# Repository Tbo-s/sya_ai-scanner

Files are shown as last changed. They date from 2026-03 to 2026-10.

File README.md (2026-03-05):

# sya_ai-scanner

Software-
arduino mega = grbl
grbl dowloaden (zip) vanuit https://github.com/gnea/grbl-Mega/tree/edge uit deze folder de grbl in de arduino folder zetten. Dit bestand dan uploaden naar mega. ''$'' typen in serial monitor (115200 baud) voor versie te checken.

starten pi
cd ~/projects/sya_ai-scanner/code/picode/visionAI

make run_backend
make run_frontend

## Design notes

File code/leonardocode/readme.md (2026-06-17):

te ontvangen :
GATE_OPEN
GATE_CLOSE
TRAY_OUT
TRAY_IN
STATUS
STOP_ALL

stoppers:
- bovenste gate-stopper: A4
- onderste gate-stopper: A5
- lade-uit-stopper: D4
- lade-in-stopper: D5
- alle stopper-switches zijn normally closed en gebruiken INPUT_PULLUP
- sluit elke stopper naar GND: niet geraakt = LOW, stopper geraakt/contact open = HIGH

leonardo verstuurd:
ACK:GATE_OPEN
ACK:GATE_CLOSE
ACK:TRAY_OUT
ACK:TRAY_IN
ACK:STATUS,gateState=...,gatePos=...,trayState=...,trayPos=...

De Pi/backend bepaalt of de gate klaar is via `STATUS`: `gateState=0` en `gatePos=UP`
of `gatePos=DOWN`.

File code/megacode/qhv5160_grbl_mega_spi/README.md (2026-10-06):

# QHV5160 on Arduino Mega GRBL

This patch configures three QHV5160/TMC5160 drivers from the Arduino Mega at
GRBL boot. It uses bit-banged SPI so every driver input has its own Mega pin
and no signal wire needs to be split. One optional wire enables X diagnostics.

For QHV5160 modules with 0.075 ohm sense resistors, all three axes use about
846 mA RMS run current (IRUN=16), 348 mA RMS hold current, and
GLOBAL_SCALER=133. These are calculated current targets, not measured coil
currents or analog Vref voltages.

All axes use full steps without interpolation to match the previous DRV8825
drivers with M0/M1/M2 disconnected. At the current GRBL setting of 250 steps/mm,
a 0.004 mm command is one full step (1.8 degrees on the bare motor shaft); a
0.1 mm command is 25 steps / 45 degrees. Begin with one step. Actual arm travel
depends on the mechanics and calibration.

## Apply

From the repo root on the Mac:

```bash
python3 code/megacode/qhv5160_grbl_mega_spi/apply_to_arduino_grbl.py
```

Then upload:

```text
code/megacode/grblUpload_copy_20260304140826/grblUpload_copy_20260304140826.ino
```

with board `Arduino Mega or Mega 2560`.

## Wiring

Set QHV5160 `VIO` to 5V and connect all grounds together.

X driver:

- Mega D24 -> `REFL_STEP`
- Mega D30 -> `DIR_REFR_DIR`
- Mega D40 -> `SCK_CFG2`
- Mega D41 -> `SDI_CFG1`
- Mega D42 -> `CSN_CFG3`

Y driver:

- Mega D25 -> `REFL_STEP`
- Mega D31 -> `DIR_REFR_DIR`
- Mega D43 -> `SCK_CFG2`
- Mega D44 -> `SDI_CFG1`
- Mega D45 -> `CSN_CFG3`

Z driver:

- Mega D26 -> `REFL_STEP`
- Mega D32 -> `DIR_REFR_DIR`
- Mega D46 -> `SCK_CFG2`
- Mega D47 -> `SDI_CFG1`
- Mega D48 -> `CSN_CFG3`

Enable:

- Minimum wiring: each QHV5160 `EN` -> GND.
- Or one shared GRBL enable line: Mega D13 -> each `EN`.

Mode pins on every driver:

- `SD_MODE` -> VIO
- `SPI_MODE` -> VIO

Leave Y/Z `SDO_CFG0` disconnected.

## Optional X Diagnostics

With all power and USB disconnected, add **X `SDO_CFG0` -> Mega D49**.
Keep the existing SCK/SDI/CSN wiring and common ground. D49 is an input with a
weak pull-up, not a 5V output. This adds just one wire (four SPI wires for X).

After uploading this patch, send `$T` through GRBL while idle or in alarm.
The command reads registers only: it does not move the motor, clear driver
faults, or change current settings.

- `IOIN`: chip version in bits 31..24 (expected 0x30), EN level in bit 4
  (0=enabled), SD_MODE in bit 6 (1=STEP/DIR mode).
- `GSTAT`: reset in bit 0, driver shutdown in bit 1, charge-pump undervoltage
  history in bit 2. Read `DRV_STATUS` for details before clearing faults.
- `GCONF`: expected 0x00000000.
- `CHOPCONF`: expected 0x08408158 for X (full steps, driver enabled). Y and Z
  receive the same setting at boot; their SDO pins are intentionally unwired.
- `DRV_STATUS`: raw driver status, including protection flags and CS_ACTUAL.
- `MSCNT`: microstep counter; compare before/after a small commanded move to
  check whether the driver is receiving STEP pulses.
- `BOOT_CURRENT_ECHO`: 1 means the driver echoed both current-setting payloads
  during Mega boot. It is not a measurement of coil current. GLOBAL_SCALER and
  IHOLD_IRUN are write-only, so `$T` does not pretend to read their contents.

All-ones reads typically mean no SDO response; all-zero reads also do not
establish communication. Check IOIN version and several register values.
`BOOT_CURRENT_ECHO=0` can also mean SDO was missing at boot; after connecting
it, restart the Mega with the driver powered before judging this field.

Reference: [TMC5160 datasheet, sections 4 and 6](https://www.analog.com/media/en/technical-documentation/data-sheets/TMC5160A_datasheet_rev1.18.pdf).

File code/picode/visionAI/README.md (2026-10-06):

# SYA VisionAI

Softwarestack voor een Raspberry Pi 4 kiosk die een smartphone automatisch scant, fotografeert en gradeert met behulp van:

- een Arduino Leonardo voor gate, lade, wrist-servo's en vacuum
- een Arduino Mega met GRBL voor X/Y/Z-beweging van de robotarm
- een USB-camera voor IMEI-detectie
- een Pi CSI-camera voor extra foto's
- een Vue frontend in kiosk mode
- een FastAPI backend die de volledige flow en hardware aanstuurt

Deze README is bedoeld als:

- opstarthandleiding voor de Raspberry Pi
- overzicht van alle belangrijke commando's
- uitleg van de code-architectuur
- referentie voor debuggen en kalibreren

## 1. Doel Van Het Project

De gebruiker legt een smartphone op een lade. Daarna:

1. leest de kiosk het IMEI-nummer
2. bepaalt de Pi het toesteltype en een richtwaarde
3. opent de gate/lade zodat het toestel in de box kan
4. positioneert de robotarm zich naar het toestel
5. pakt de arm het toestel op met vacuum
6. draait de arm/wrist het toestel voor de camera
7. maakt het systeem foto's van de voor- en achterkant
8. stuurt de backend foto's en IMEI naar een damage/pricing service
9. toont de kiosk het resultaat en een prijsvoorstel

De uiteindelijke flow in code is gemodelleerd in [`backend/services/scan_orchestrator.py`](/Users/tbo/Desktop/github/sya_ai-scanner/code/picode/visionAI/backend/services/scan_orchestrator.py).

## 2. Hardware Overzicht

### Raspberry Pi 4

- draait frontend + backend
- praat via USB met Leonardo en Mega
- leest de USB-camera uit voor IMEI
- kan optioneel de Pi CSI-camera gebruiken voor extra foto's

### Arduino Leonardo

Wordt aangesproken via `pyserial` en stuurt:

- gate open/dicht
- lade in/uit
- 2 wrist-servo's
- vacuum aan/uit

Ondersteunde commando's in de Python-code:

- `GATE_OPEN`
- `GATE_CLOSE`
- `TRAY_OUT`
- `TRAY_IN`
- `GATE_POS`
- `STATUS`
- `VACUUM_ON`
- `VACUUM_OFF`

Stopper-switches op de Leonardo:

- bovenste gate-stopper: `A4`
- onderste gate-stopper: `A5`
- lade-uit-stopper: `D4`
- lade-in-stopper: `D5`
- alle stopper-switches zijn normally closed en gebruiken `INPUT_PULLUP`
- sluit elke switch naar `GND`: niet geraakt = `LOW`, stopper geraakt/contact open = `HIGH`

Belangrijke responses:

- `ACK:GATE_OPEN`
- `ACK:GATE_CLOSE`
- `ACK:TRAY_OUT`
- `ACK:TRAY_IN`
- `ACK:STATUS,gateState=...,gatePos=...,trayState=...,trayPos=...`
- `GATE_POS=UP`
- `GATE_POS=DOWN`
- `ERR:...`

De backend bepaalt of een gatebeweging klaar is via `STATUS`: `gateState=0` en
`gatePos=UP` of `gatePos=DOWN`.

De Leonardo-logica zit vooral in:

- [`backend/services/machine_service.py`](/Users/tbo/Desktop/github/sya_ai-scanner/code/picode/visionAI/backend/services/machine_service.py)
- [`backend/controller/arduino.py`](/Users/tbo/Desktop/github/sya_ai-scanner/code/picode/visionAI/backend/controller/arduino.py)

### Arduino Mega + GRBL

Stuurt:

- X/Y-beweging
- Z-as

De carriage is mechanisch cartesiaans. De interface zet de zichtbare pijlen om
naar de gedraaide Mega-motorassen: boven/onder gebruikt Mega X en links/rechts
gebruikt Mega Y met omgekeerde richting. `APP_GRBL_COREXY_ENABLED` blijft
beschikbaar voor een eventuele echte CoreXY-opstelling, maar staat uit.

De Mega/GRBL-logica zit in:

- [`backend/services/grbl_service.py`](/Users/tbo/Desktop/github/sya_ai-scanner/code/picode/visionAI/backend/services/grbl_service.py)
- [`backend/controller/arduino.py`](/Users/tbo/Desktop/github/sya_ai-scanner/code/picode/visionAI/backend/controller/arduino.py)

## 3. Repo Structuur

### Backend

- [`backend/websrv.py`](/Users/tbo/Desktop/github/sya_ai-scanner/code/picode/visionAI/backend/websrv.py)
  FastAPI app, router-registratie, websocket endpoint, frontend serving, boot initialization.

- [`backend/controller/scan.py`](/Users/tbo/Desktop/github/sya_ai-scanner/code/picode/visionAI/backend/controller/scan.py)
  HTTP API voor scan start, confirm, status en abort.

- [`backend/services/scan_orchestrator.py`](/Users/tbo/Desktop/github/sya_ai-scanner/code/picode/visionAI/backend/services/scan_orchestrator.py)
  De belangrijkste machineflow. Hier staan de stappen 19-60 van jouw flowchart.

- [`backend/controller/camera.py`](/Users/tbo/Desktop/github/sya_ai-scanner/code/picode/visionAI/backend/controller/camera.py)
  USB-camera stream, IMEI detectie, scanfoto's en Pi CSI captures.

- [`backend/services/machine_service.py`](/Users/tbo/Desktop/github/sya_ai-scanner/code/picode/visionAI/backend/services/machine_service.py)
  Alle Leonardo-gerelateerde hardwareacties.

- [`backend/services/grbl_service.py`](/Users/tbo/Desktop/github/sya_ai-scanner/code/picode/visionAI/backend/services/grbl_service.py)
  Alle GRBL/NEMA-bewegingen.

- [`backend/services/ai_damage_service.py`](/Users/tbo/Desktop/github/sya_ai-scanner/code/picode/visionAI/backend/services/ai_damage_service.py)
  Mock of echte API-call voor damage/pricing-resultaat.

- [`backend/services/system_service.py`](/Users/tbo/Desktop/github/sya_ai-scanner/code/picode/visionAI/backend/services/system_service.py)
  Boot-safe-idle, home en runtime settings.

- [`backend/controller/system.py`](/Users/tbo/Desktop/github/sya_ai-scanner/code/picode/visionAI/backend/controller/system.py)
  Debug/system endpoints om de machine in veilige toestand te zetten.

- [`backend/controller/device_lookup.py`](/Users/tbo/Desktop/github/sya_ai-scanner/code/picode/visionAI/backend/controller/device_lookup.py)
  Mock lookup van IMEI naar toesteltype en maximale waarde.

### Frontend

- [`frontend/src/pages/index.vue`](/Users/tbo/Desktop/github/sya_ai-scanner/code/picode/visionAI/frontend/src/pages/index.vue)
  De kioskflow voor de gebruiker: starten, IMEI scannen, toestel bevestigen, scanstatus volgen, resultaat tonen.

- [`frontend/src/services/websocket.js`](/Users/tbo/Desktop/github/sya_ai-scanner/code/picode/visionAI/frontend/src/services/websocket.js)
  Websocket client voor real-time `scan_event` updates.

### Deploy / Scripts

- [`scripts/pi_run_backend.sh`](/Users/tbo/Desktop/github/sya_ai-scanner/code/picode/visionAI/scripts/pi_run_backend.sh)
  Start de backend op de Pi.

- [`scripts/pi_build_frontend.sh`](/Users/tbo/Desktop/github/sya_ai-scanner/code/picode/visionAI/scripts/pi_build_frontend.sh)
  Bouwt de frontend productieversie.

- [`scripts/pi_start_kiosk.sh`](/Users/tbo/Desktop/github/sya_ai-scanner/code/picode/visionAI/scripts/pi_start_kiosk.sh)
  Start Chromium in kiosk mode.

- [`deploy/systemd/sya-backend.service`](/Users/tbo/Desktop/github/sya_ai-scanner/code/picode/visionAI/deploy/systemd/sya-backend.service)
  Systemd unit voor backend.

- [`deploy/systemd/sya-kiosk.service`](/Users/tbo/Desktop/github/sya_ai-scanner/code/picode/visionAI/deploy/systemd/sya-kiosk.service)
  Systemd unit voor kiosk/browser.

## 4. Raspberry Pi Setup

### 4.0 Snelle recovery na nieuwe SD-kaart

Flash Raspberry Pi OS, maak gebruiker `sya` aan en zet SSH aan. Daarna:

```bash
cd /home/sya
git clone <jouw-repo-url> sya
cd /home/sya/sya
./scripts/pi_first_boot_setup.sh
```

Laat `APP_GRBL_HOME_ON_BOOT=0` staan tot X/Y/Z limit-switches met
`/api/arduino/grbl/status` of een raw `?` GRBL-status bewezen schakelen.
Zet homing pas daarna terug aan.

### 4.1 Repo clonen

```bash
cd /home/sya
git clone <jouw-repo-url> sya
cd sya
```

### 4.2 Systeempackages installeren

```bash
sudo apt update
sudo apt install -y python3 python3-venv python3-pip libzbar0 chromium-browser
```

Voor Pi CSI camera:

```bash
sudo apt install -y python3-picamera2
```

### 4.3 Project dependencies installeren

```bash
make install
```

Wat dit doet:

- maakt `backend/venv`
- installeert Python dependencies uit `backend/requirements.txt`
- installeert frontend dependencies uit `frontend/package.json`

### 4.4 Config invullen

Open:

```bash
nano backend/config/config.env
```

Belangrijkste variabelen:

- `APP_LEONARDO_PORT`
- `APP_GRBL_PORT`
- `APP_LEONARDO_BAUD`
- `APP_GRBL_BAUD`
- `APP_CAMERA_INDEX`
- `APP_PHOTO_STORAGE_DIR`
- `APP_PI_CAPTURE_DIR`
- `APP_FRONTEND_DIST`
- `APP_GRBL_FRONT_X`
- `APP_GRBL_FRONT_Y`
- `APP_GRBL_BACK_X`
- `APP_GRBL_BACK_Y`
- `APP_GRBL_Z_AXIS_ENABLED`
- `APP_GRBL_Z_PICKUP`
- `APP_GRBL_Z_TRAVEL`
- `APP_GRBL_HOME_Z_CLEARANCE`
- `APP_GRBL_HOME_Z_STEP`
- `APP_GRBL_HOME_Z_SEARCH_DISTANCE`
- `APP_GRBL_HOME_Z_FEED_RATE`
- `APP_GRBL_Z_LIMIT_TOWARD_ZERO_SIGN`
- `APP_ARM_DISTANCE_THRESHOLD_CM`
- `APP_GATE_MOVE_TIMEOUT_S`
- `APP_TRAY_MOVE_TIMEOUT_S`
- `APP_USER_CONFIRM_TIMEOUT_S`
- `APP_MACHINE_SAFE_IDLE_ON_BOOT`
- `APP_DEVICE_LOOKUP_API_ENABLED`
- `APP_DEVICE_LOOKUP_API_URL`
- `APP_DEVICE_LOOKUP_API_TIMEOUT_S`
- `APP_AI_DAMAGE_API_MOCK`
- `APP_AI_DAMAGE_API_URL`
- `APP_SCAN_RESULTS_UPLOAD_ENABLED`
- `APP_SCAN_RESULTS_UPLOAD_URL`
- `APP_SCAN_RESULTS_UPLOAD_TIMEOUT_S`
- `APP_SCAN_RESULTS_UPLOAD_REQUIRED`

De documentatie van die env vars staat in:

- [`backend/config/config.env`](/Users/tbo/Desktop/github/sya_ai-scanner/code/picode/visionAI/backend/config/config.env)
- [`backend/config/README.md`](/Users/tbo/Desktop/github/sya_ai-scanner/code/picode/visionAI/backend/config/README.md)

## 5. Frontend / Backend Opstarten

### 5.1 Development mode

Backend:

```bash
make run_backend
```

Frontend:

```bash
make run_frontend
```

Samen:

```bash
make run
```

In development:

- frontend draait normaal op `http://localhost:8080`
- backend draait op `http://localhost:3000`

### 5.2 Productie / Pi mode

Frontend builden:

```bash
./scripts/pi_build_frontend.sh
```

Backend starten:

```bash
./scripts/pi_run_backend.sh
```

Dan serveert de backend de gebouwde frontend op:

```text
http://<raspberry-pi-ip>:3000
```

### 5.3 Chromium kiosk starten

Op de Pi met een actieve desktop-sessie:

```bash
./scripts/pi_start_kiosk.sh http://127.0.0.1:3000
```

## 6. Systemd Boot Op De Pi

De bedoeling is dat backend en kiosk automatisch starten bij opstarten van de Pi.

Installeer de services:

```bash
sudo cp deploy/systemd/sya-backend.service /etc/systemd/system/
sudo cp deploy/systemd/sya-kiosk.service /etc/systemd/system/
sudo systemctl daemon-reload
sudo systemctl enable sya-backend.service
sudo systemctl enable sya-kiosk.service
sudo systemctl start sya-backend.service
sudo systemctl start sya-kiosk.service
```

Status controleren:

```bash
sudo systemctl status sya-backend.service
sudo systemctl status sya-kiosk.service
```

Logs bekijken:

```bash
journalctl -u sya-backend.service -f
journalctl -u sya-kiosk.service -f
```

## 7. Runtime Flow In De Code

### 7.1 Gebruikersflow

De frontend in [`frontend/src/pages/index.vue`](/Users/tbo/Desktop/github/sya_ai-scanner/code/picode/visionAI/frontend/src/pages/index.vue) doet:

1. startscherm tonen
2. case/screenprotector schoonmaakflow
3. IMEI scannen met USB-camera
4. manuele IMEI fallback aanbieden
5. toesteldata ophalen
6. gebruiker toestel laten uitschakelen
7. backend scan starten via `/api/scan/start`
8. live machine-updates ontvangen via websocket
9. eindprijs/resultaat tonen

### 7.2 Scan flow

De backend scanflow zit in [`backend/services/scan_orchestrator.py`](/Users/tbo/Desktop/github/sya_ai-scanner/code/picode/visionAI/backend/services/scan_orchestrator.py).

Belangrijk:

- `start_scan()`
  Start een nieuwe scan en maakt een `ScanSession`.

- `_await_user()`
  Pauzeert de flow wanneer de gebruiker het toestel nog moet plaatsen.

- `_step()`
  Draait een hardwarefunctie in een thread en broadcast de status.

- `_execute_sequence()`
  Bevat de volledige fysieke machineflow.

### 7.3 Leonardo logica

[`backend/services/machine_service.py`](/Users/tbo/Desktop/github/sya_ai-scanner/code/picode/visionAI/backend/services/machine_service.py) is de laag die letterlijk met de Leonardo praat.

Belangrijke functies:

- `open_gate()`
- `close_gate()`
- `tray_out()`
- `tray_in()`
- `wait_for_gate_done()`
- `wait_for_tray_done()`
- `set_wrist1()`
- `set_wrist2()`
- `wrist_home()`
- `vacuum_on()`
- `vacuum_off()`
- `read_distance()`

### 7.4 GRBL logica

[`backend/services/grbl_service.py`](/Users/tbo/Desktop/github/sya_ai-scanner/code/picode/visionAI/backend/services/grbl_service.py) praat met de Mega via GRBL.

Belangrijke functies:

- `send_grbl()`
- `move_to_front_of_phone()`
- `move_to_back_of_phone()`
- `move_to_front_slow_with_distance_stop()`
- `move_to_back_slow_with_distance_stop()`
- `z_up()`
- `z_down()`
- `run_sequence()`
- `run_postflow_sequence()`

### 7.5 Camera logica

[`backend/controller/camera.py`](/Users/tbo/Desktop/github/sya_ai-scanner/code/picode/visionAI/backend/controller/camera.py) beheert:

- live USB-camera stream via `/api/camera/stream`
- IMEI detectie via `/api/imei/detect`
- scanfoto's via `take_photo()`
- Pi CSI captures via `/api/camera/pi/capture`

### 7.6 Device lookup / pricing mock

[`backend/controller/device_lookup.py`](/Users/tbo/Desktop/github/sya_ai-scanner/code/picode/visionAI/backend/controller/device_lookup.py) gebruikt standaard een lokale JSON lookup om een toesteltype, grootte en maximumwaarde te geven.
Zet `APP_DEVICE_LOOKUP_API_ENABLED=1` en `APP_DEVICE_LOOKUP_API_URL=...` om later een echte IMEI/product-API aan te sluiten.

[`backend/services/ai_damage_service.py`](/Users/tbo/Desktop/github/sya_ai-scanner/code/picode/visionAI/backend/services/ai_damage_service.py) geeft:

- mock-resultaten als `APP_AI_DAMAGE_API_MOCK=1`
- echte API-calls met IMEI, sessie, maximumwaarde en alle foto's als `APP_AI_DAMAGE_API_MOCK=0`

[`backend/services/scan_upload_service.py`](/Users/tbo/Desktop/github/sya_ai-scanner/code/picode/visionAI/backend/services/scan_upload_service.py) kan na een volledige scan een aparte POST sturen met IMEI, sessie, toestelmodel, maximumwaarde, AI-resultaat en alle foto's als base64 JSON. Standaard staat dit uit:

- `APP_SCAN_RESULTS_UPLOAD_ENABLED=0`
- `APP_SCAN_RESULTS_UPLOAD_URL=`

Vul later de URL in en zet `APP_SCAN_RESULTS_UPLOAD_ENABLED=1` om de POST effectief te sturen. Met `APP_SCAN_RESULTS_UPLOAD_REQUIRED=1` faalt de scan-flow als deze upload mislukt; standaard wordt een uploadfout alleen gerapporteerd in `upload_result`.

## 8. API Endpoints

### Scan

- `POST /api/scan/start`
- `POST /api/scan/confirm`
- `POST /api/scan/abort`
- `GET /api/scan/status`

De automatische UI-flow gebruikt een expliciete state machine in plaats van losse
stapnummers: `BOOT`, `WELCOME`, `IMEI_SCAN`, `DEVICE_LOOKUP`, `WAIT_POWER_OFF`,
`LOAD_DEVICE`, `CLOSE_BOX`, `CAPTURE_FRONT`, `CAPTURE_BACK`, `UPLOAD_RESULTS`,
`RETURN_DEVICE`, `SHOW_PRICE`, `DONE`, `ERROR` en `EMERGENCY_STOP`. Hardware-substeps
worden alleen nog als detailinformatie meegestuurd via websocket-events.

### Camera

- `GET /api/camera/stream`
- `GET /api/imei/detect`
- `POST /api/camera/capture`
- `POST /api/camera/pi/capture`

### Device lookup

- `POST /api/device/lookup`

### Arduino / hardware debug

- `POST /api/arduino/servo`
- `POST /api/arduino/leonardo/servo`
- `POST /api/arduino/leonardo/gate`
- `GET /api/arduino/leonardo/gate-position`
- `POST /api/arduino/leonardo/tray`
- `GET /api/arduino/leonardo/tray-position`
- `POST /api/arduino/leonardo/home`
- `POST /api/arduino/leonardo/emergency-stop`
- `POST /api/arduino/grbl/command`
- `POST /api/arduino/grbl/unlock`
- `POST /api/arduino/grbl/home`
- `POST /api/arduino/grbl/home-xy`
- `POST /api/arduino/grbl/stop`
- `POST /api/arduino/grbl/post-flow`
- `GET /api/arduino/ports`

### System

- `GET /api/system/settings`
- `POST /api/system/safe-idle`
- `POST /api/system/home`
- `GET /api/system/boot-report`

## 9. Websocket Events

Frontend en backend communiceren live via `/ws`.

Belangrijkste event:

- `scan_event`

Types:

- `awaiting_user`
- `step_complete`
- `scan_complete`
- `scan_failed`

Frontend-afhandeling zit in [`frontend/src/services/websocket.js`](/Users/tbo/Desktop/github/sya_ai-scanner/code/picode/visionAI/frontend/src/services/websocket.js) en [`frontend/src/pages/index.vue`](/Users/tbo/Desktop/github/sya_ai-scanner/code/picode/visionAI/frontend/src/pages/index.vue).

## 10. Test- En Debugcommando's

Seriële poorten opvragen:

```bash
curl http://127.0.0.1:3000/api/arduino/ports
```

Gate positie lezen:

```bash
curl http://127.0.0.1:3000/api/arduino/leonardo/gate-position
```

Tray positie lezen:

```bash
curl http://127.0.0.1:3000/api/arduino/leonardo/tray-position
```

Machine in veilige idle toestand zetten:

```bash
curl -X POST http://127.0.0.1:3000/api/system/safe-idle
```

Home flow uitvoeren:

```bash
curl -X POST http://127.0.0.1:3000/api/system/home
```

GRBL unlock/home:

```bash
curl -X POST http://127.0.0.1:3000/api/arduino/grbl/unlock
curl -X POST http://127.0.0.1:3000/api/arduino/grbl/home
```

`/api/arduino/grbl/home` voert de volledige arm-homeflow uit: Z eerst `+2 mm`,
daarna X/Y naar hun limits, daarna Z in stappen van `-1 mm` tot de Z-limit onderaan
geraakt wordt. De exacte waarden zijn configureerbaar met `APP_GRBL_HOME_Z_*`.
De homingfeedrates staan standaard traag ingesteld: X/Y `F60` en Z `F30`.
Zet `APP_GRBL_Z_AXIS_ENABLED=0` om tijdelijk alle Z-bewegingen over te slaan wanneer
de Z-driver niet aangesloten is. Homing doet dan alleen X/Y en Z-knoppen in de UI worden
uitgeschakeld.
Voor homing wordt eerst een live GRBL-status gelezen. Als X/Y al op hun limit-switch
staan, worden die assen direct als `0` gezet en niet verder tegen de stopper bewogen.
Als de switchstatus niet gelezen kan worden, wordt homing afgebroken in plaats van blind
een beweging te sturen.

Frontend build:

```bash
./scripts/pi_build_frontend.sh
```

Backend starten:

```bash
./scripts/pi_run_backend.sh
```

## 11. Kalibratiepunten

Voor echte productie moet je minstens deze parameters op de hardware afstemmen:

- `APP_GRBL_FRONT_X`
- `APP_GRBL_FRONT_Y`
- `APP_GRBL_BACK_X`
- `APP_GRBL_BACK_Y`
- `APP_GRBL_Z_AXIS_ENABLED`
- `APP_GRBL_Z_PICKUP`
- `APP_GRBL_Z_TRAVEL`
- `APP_ARM_DISTANCE_THRESHOLD_CM`
- `APP_WRIST_DWELL_MS`
- `APP_GATE_MOVE_TIMEOUT_S`
- `APP_TRAY_MOVE_TIMEOUT_S`
- `APP_VACUUM_DWELL_S`

Praktisch:

- test eerst zonder echte smartphone
- test daarna met dummy toestel
- pas daarna met echte smartphone
- zet `APP_AI_DAMAGE_API_MOCK=1` tijdens mechanische integratie
- zet `APP_DEVICE_LOOKUP_API_ENABLED=0` zolang de echte IMEI/product-API nog niet bestaat

## 12. Belangrijke Opmerkingen

- De code is klaar als softwarebasis voor de Pi, maar de echte betrouwbaarheid hangt af van mechanische kalibratie.
- De Leonardo firmware en GRBL settings moeten overeenkomen met de verwachte commando's en posities in deze repo.
- De notes/Arango stukken zijn nog aanwezig uit de oorspronkelijke template, maar zijn niet kritisch voor de scannerflow.
- Voor een echte live uitrol raad ik aan om eerst alle `/api/system/*` en `/api/arduino/*` debug endpoints stap voor stap op de Pi te testen.

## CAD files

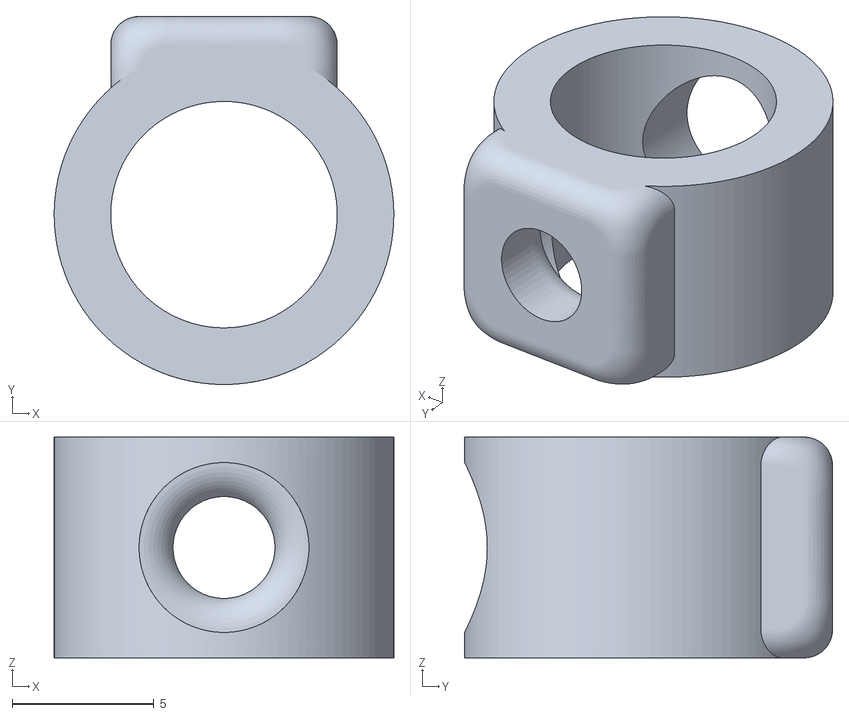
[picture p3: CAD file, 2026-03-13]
3D_files/ARM/arm-part8(4X).stl
12.0 x 13.0 x 7.80

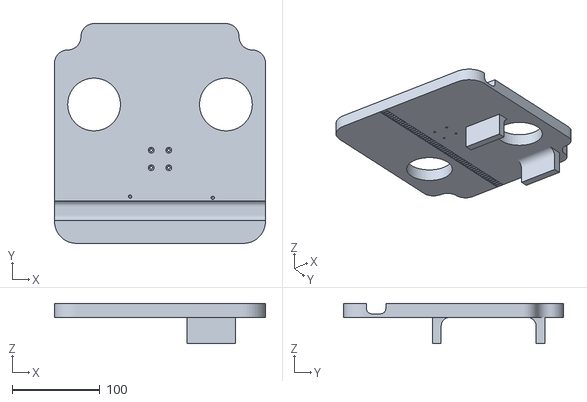
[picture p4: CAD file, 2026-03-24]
3D_files/gate/justatest.stl
240.0 x 250.0 x 46.0

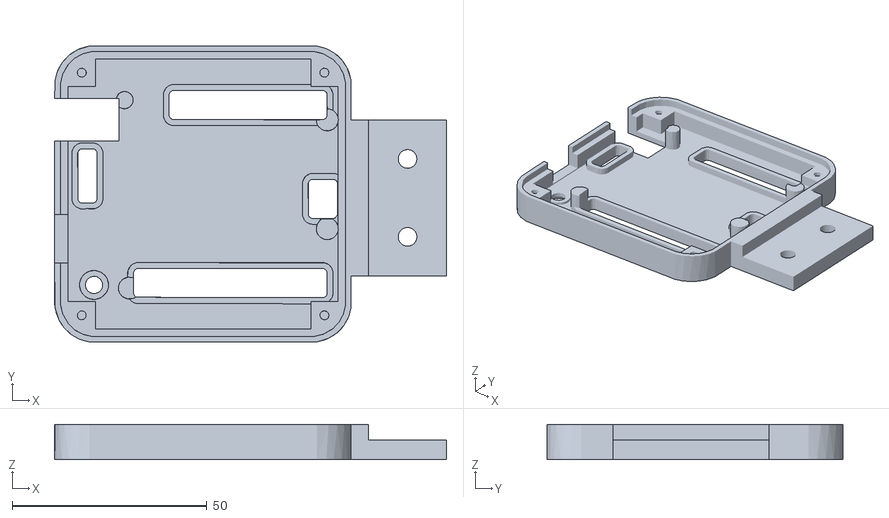
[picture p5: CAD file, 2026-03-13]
3D_files/part-casings/leaonardo_top.stl
100.7 x 76.0 x 9.00

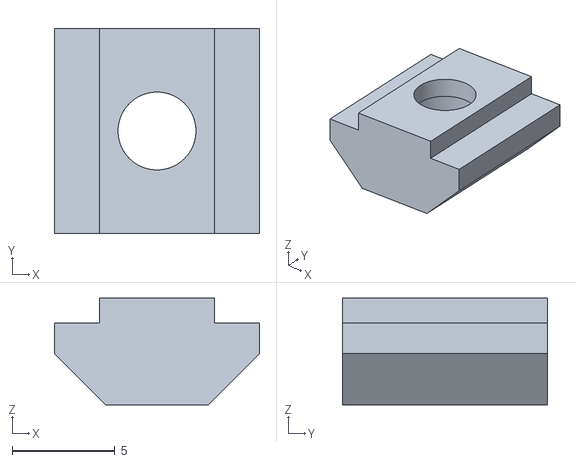
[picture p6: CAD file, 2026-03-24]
3D_files/structure/3mm_2020_adapter_heatinsert.stl
10.0 x 10.00 x 5.20

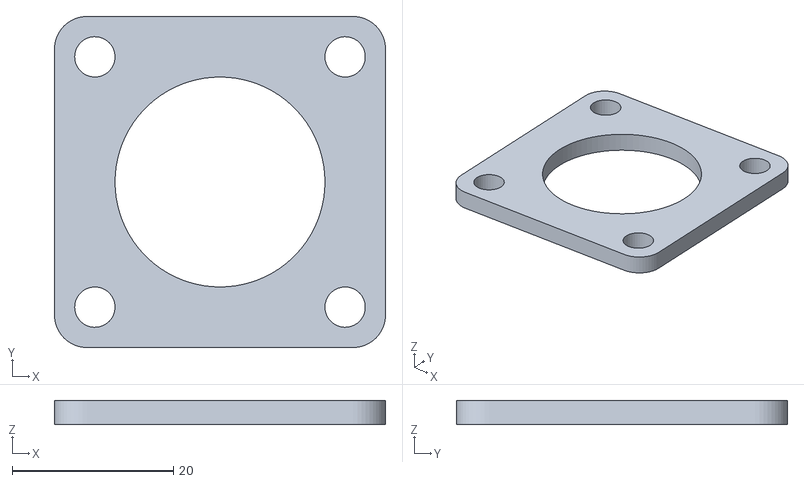
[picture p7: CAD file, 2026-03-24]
3D_files/xy-parts/NEMA17_spacer.stl
41.0 x 41.0 x 3.00

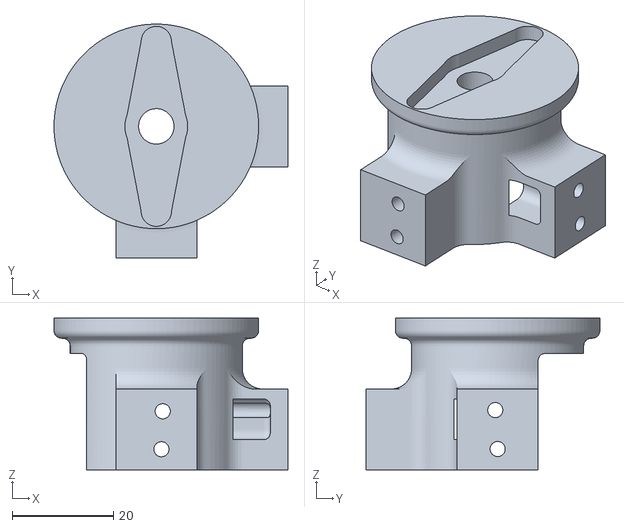
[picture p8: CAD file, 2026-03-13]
3D_files/ARM/arm-part5.stl
46.2 x 46.2 x 30.0

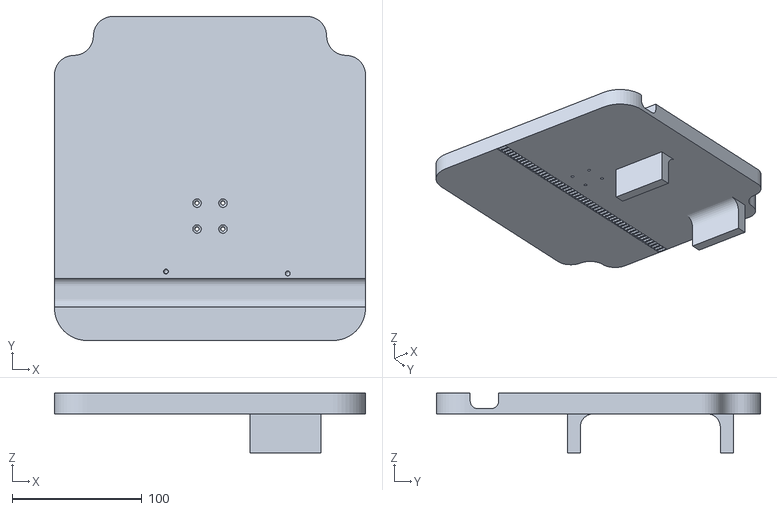
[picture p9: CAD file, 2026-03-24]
3D_files/gate/phone-loader-base.stl
240.0 x 250.0 x 46.0

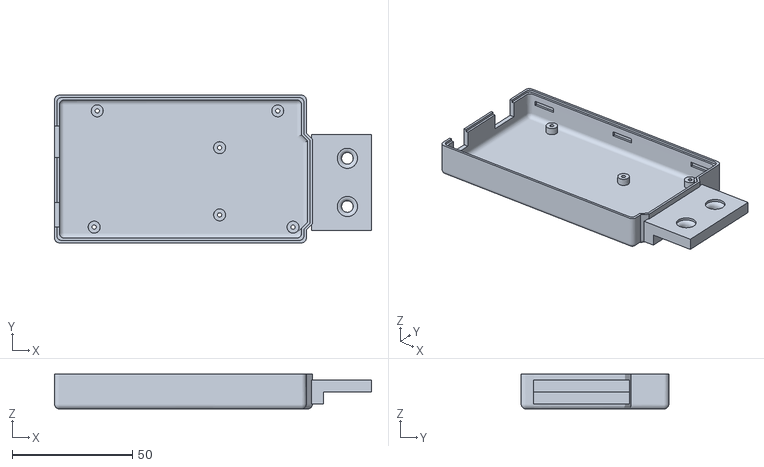
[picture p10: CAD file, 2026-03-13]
3D_files/part-casings/mega_bottem.stl
131.6 x 61.3 x 14.5

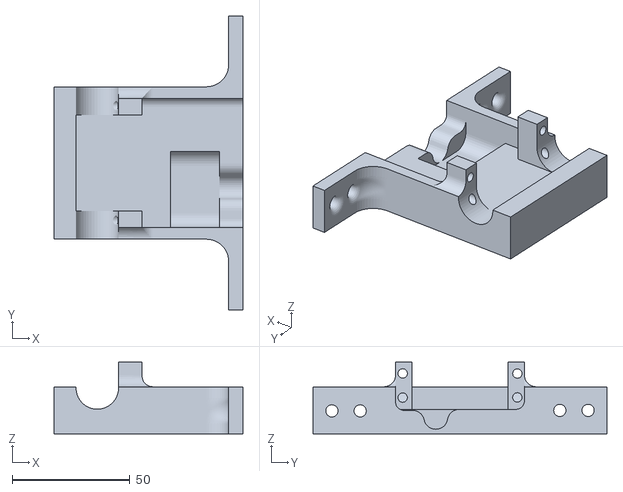
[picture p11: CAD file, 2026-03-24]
3D_files/phone-loader/motor-adapter-fixed.stl
80.0 x 124.6 x 30.5

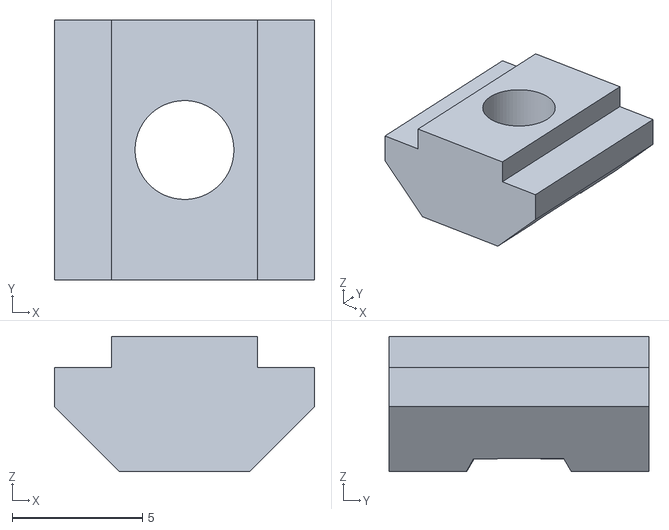
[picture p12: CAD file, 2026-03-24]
3D_files/structure/3MM_2020_adapter.stl
10.00 x 10.00 x 5.20

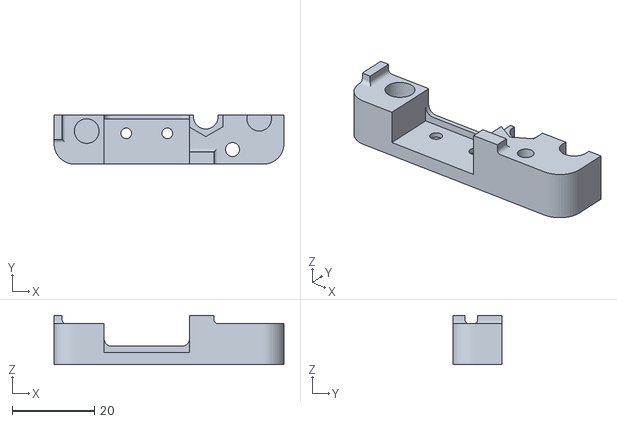
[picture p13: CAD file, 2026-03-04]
3D_files/xy-parts/x-carry4-Left.stl
56.0 x 12.0 x 12.0

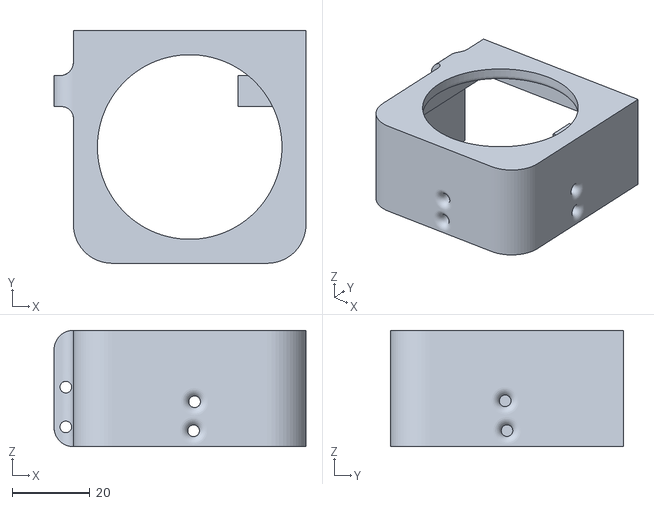
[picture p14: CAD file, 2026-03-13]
3D_files/ARM/arm-part4.stl
65.0 x 60.0 x 30.0

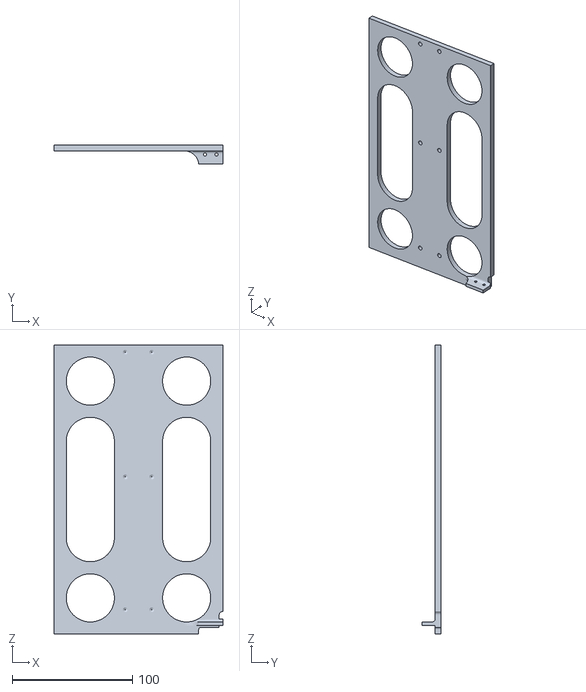
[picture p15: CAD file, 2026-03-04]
3D_files/gate/gate-part2.stl
140.0 x 16.0 x 240.0

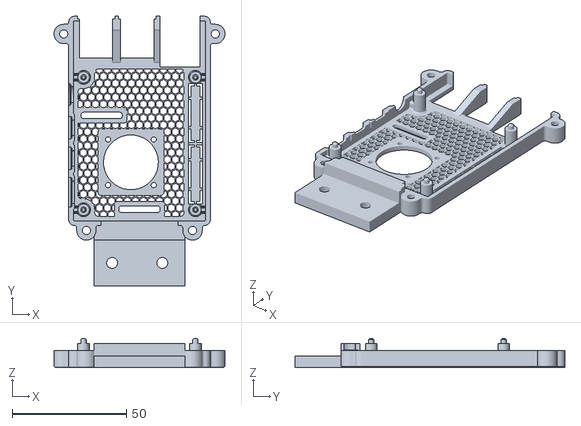
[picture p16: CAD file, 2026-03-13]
3D_files/part-casings/pi-top.stl
74.9 x 118.0 x 12.7

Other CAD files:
3D_files/phone-loader/motor-adapter.stl
3D_files/structure/tandwiel(small).stl
3D_files/xy-parts/x-carry4-Right.stl
3D_files/ARM/arm-part1.stl
3D_files/ARM/arm-part2.stl
3D_files/ARM/arm-part3.stl
3D_files/ARM/arm-part6.stl
3D_files/ARM/arm-part7(4X).stl
3D_files/gate/gate-motor-adapter.stl
3D_files/gate/gate-motor.stl
3D_files/gate/gate-part1.stl
3D_files/gate/gate-part3.stl
3D_files/gate/gate-part4.stl
3D_files/gate/gate-part5.stl
3D_files/gate/tandwiel_rack.stl
3D_files/part-casings/Leonardo_bottem.stl
3D_files/part-casings/mega_top.stl
3D_files/part-casings/pi_bottem.stl
3D_files/part-casings/picam.stl
3D_files/part-casings/switch.stl
3D_files/part-casings/vacuum-part1-left.stl
3D_files/part-casings/vacuum-part1-right.stl
3D_files/part-casings/vacuum-part2-left.stl
3D_files/part-casings/vacuum-part2-right.stl
3D_files/part-casings/voeding-case.stl
3D_files/structure/2020brackets.stl
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

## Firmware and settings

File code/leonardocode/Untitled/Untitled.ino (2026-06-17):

#include <Wire.h>
#include <SparkFun_VL53L1X.h>
#include <Servo.h>
#include <string.h>
#include <stdlib.h>

// =========================
// Serial parser
// =========================
const byte CMD_BUFFER_SIZE = 64;
char usbCmdBuffer[CMD_BUFFER_SIZE];
byte usbCmdIndex = 0;
char runtimeCmdBuffer[CMD_BUFFER_SIZE];
byte runtimeCmdIndex = 0;

// =========================
// Distance sensor
// =========================
SFEVL53L1X distanceSensor;
bool distanceSensorOk = false;
uint16_t lastDistanceMm = 0;
uint16_t lastRawDistanceMm = 0;
uint16_t lastDisplayDistanceMm = 0;
uint8_t lastDistanceRangeStatus = 255;
unsigned long lastDistanceUpdateMs = 0;

// =========================
// Servo objects
// =========================
Servo servoGate;
Servo servoPhoneLoader;
Servo servoWrist1;
Servo servoWrist2;

// =========================
// Pins
// =========================
const int gateServoPin        = 9;
const int phoneLoaderServoPin = 10;
const int wrist1ServoPin      = 11;
const int wrist2ServoPin      = 12;

const int gateOpenSwitch  = A4;  // bovenste gate-stopper
const int gateCloseSwitch = A5;  // onderste gate-stopper
const int trayOutSwitch   = 4;
const int trayInSwitch    = 5;

// All stopper switches are normally closed to GND with INPUT_PULLUP:
// idle/not hit = LOW, hit/opened = HIGH.
const int STOPPER_SWITCH_TRIGGERED_LEVEL = HIGH;

const int vacuumMotor1Pin = 6;
const int vacuumMotor2Pin = A1;
const int valve1Pin       = 8;
const int valve2Pin       = A0;

// =========================
// Servo values
// =========================
const int SERVO_STOP = 90;

const int GATE_OPEN_SPEED  = 180;
const int GATE_CLOSE_SPEED = 0;

const int TRAY_OUT_SPEED = 180;
const int TRAY_IN_SPEED  = 0;

// Wrist 1 uses calibrated reference points on the 270-degree servo:
// - back:   logical 32  -> physical 77
// - rest:   logical 93  -> physical 138
// - front:  logical 152 -> physical 197
const int WRIST1_LOGICAL_MIN_ANGLE = 32;
const int WRIST1_LOGICAL_CENTER_ANGLE = 93;
const int WRIST1_LOGICAL_MAX_ANGLE = 152;
const int WRIST1_LEFT_PHYSICAL_ANGLE = 77;
const int WRIST1_CENTER_PHYSICAL_ANGLE = 138;
const int WRIST1_RIGHT_PHYSICAL_ANGLE = 197;

// Wrist extended range
const int WRIST2_LOGICAL_MIN_ANGLE = -90;
const int WRIST2_LOGICAL_MAX_ANGLE = 90;
const int WRIST2_LEFT_PHYSICAL_ANGLE = -14;
const int WRIST2_CENTER_PHYSICAL_ANGLE = 83;
const int WRIST2_RIGHT_PHYSICAL_ANGLE = 190;

const int WRIST1_LEFT_US = 500;
const int WRIST1_CENTER_US = 1500;
const int WRIST1_RIGHT_US = 2500;
const int WRIST2_LEFT_US = 380;
const int WRIST2_CENTER_US = 1490;
const int WRIST2_RIGHT_US = 2800;
const int WRIST2_DIRECT_MIN_US = 300;
const int WRIST2_DIRECT_MAX_US = 2900;

int wrist1Angle = WRIST1_LOGICAL_CENTER_ANGLE;
int wrist1PhysicalAngle = WRIST1_CENTER_PHYSICAL_ANGLE;
int wrist1CurrentUs = WRIST1_CENTER_US;
int wrist2Angle = 0;
int wrist2PhysicalAngle = WRIST2_CENTER_PHYSICAL_ANGLE;
int wrist2CurrentUs = WRIST2_CENTER_US;

// =========================
// States
// =========================
enum GateState {
  GATE_IDLE,
  GATE_OPENING,
  GATE_CLOSING
};

enum TrayState {
  TRAY_IDLE,
  TRAY_OPENING,
  TRAY_CLOSING
};

enum GatePosition {
  GATE_UNKNOWN_POS,
  GATE_UP,
  GATE_DOWN
};

enum TrayPosition {
  TRAY_UNKNOWN_POS,
  TRAY_OUT_POS,
  TRAY_IN_POS
};

GateState gateState = GATE_IDLE;
TrayState trayState = TRAY_IDLE;
GatePosition gatePosition = GATE_UNKNOWN_POS;
TrayPosition trayPosition = TRAY_UNKNOWN_POS;

// =========================
// Forward declarations
// =========================
void readSerialNonBlocking(Stream &input, Print &output, char *cmdBuffer, byte &cmdIndex);
void processCommand(Print &output, const char *cmd);

void stopGate();
void stopTray();
bool isGateOpenStopPressed();
bool isGateCloseStopPressed();
bool hasGateStopConflict();
bool isTrayOutStopPressed();
bool isTrayInStopPressed();
bool hasTrayStopConflict();

void setWrist1Angle(int logicalAngle);
void setWrist2Angle(int logicalAngle);
void setWrist2Microseconds(int pulseUs);
int angleToMicroseconds(int angle, int minAngle, int maxAngle, int minUs, int maxUs);
int wrist1LogicalToPhysicalAngle(int logicalAngle);
int wrist1LogicalToMicroseconds(int logicalAngle);
int wrist2LogicalToPhysicalAngle(int logicalAngle);
int wrist2LogicalToMicroseconds(int logicalAngle);
int wrist2MicrosecondsToPhysicalAngle(int pulseUs);
int wrist2MicrosecondsToLogicalAngle(int pulseUs);

void updateGate();
void updateTray();

void updateGatePositionFromSwitches();
void updateTrayPositionFromSwitches();

void initDistanceSensor();
void updateDistanceMeasurement();
void updateDisplayDistance(uint16_t distance, uint8_t rangeStatus);
bool hasValidDistanceMeasurement();
bool hasDisplayDistanceMeasurement();

void printStatus(Print &output);
void printGatePositionValue(Print &output);
void printGatePositionValueInline(Print &output);
void printTrayPositionValue(Print &output);
void printTrayPositionValueInline(Print &output);

// =========================
// Setup
// =========================
void setup() {
  Serial.begin(115200);
  Serial1.begin(115200);
  Wire.begin();

  servoGate.attach(gateServoPin);
  servoPhoneLoader.attach(phoneLoaderServoPin);
  servoWrist1.attach(wrist1ServoPin);
  servoWrist2.attach(wrist2ServoPin);

  pinMode(gateOpenSwitch, INPUT_PULLUP);
  pinMode(gateCloseSwitch, INPUT_PULLUP);
  pinMode(trayOutSwitch, INPUT_PULLUP);
  pinMode(trayInSwitch, INPUT_PULLUP);

  pinMode(vacuumMotor1Pin, OUTPUT);
  pinMode(vacuumMotor2Pin, OUTPUT);
  pinMode(valve1Pin, OUTPUT);
  pinMode(valve2Pin, OUTPUT);

  stopGate();
  stopTray();

  setWrist1Angle(wrist1Angle);
  setWrist2Angle(wrist2Angle);

  digitalWrite(vacuumMotor1Pin, LOW);
  digitalWrite(vacuumMotor2Pin, LOW);
  digitalWrite(valve1Pin, LOW);
  digitalWrite(valve2Pin, LOW);

  updateGatePositionFromSwitches();
  updateTrayPositionFromSwitches();

  initDistanceSensor();

  Serial.println("READY:LEONARDO");
  Serial1.println("READY:LEONARDO");
}

// =========================
// Loop
// =========================
void loop() {
  readSerialNonBlocking(Serial1, Serial1, runtimeCmdBuffer, runtimeCmdIndex);
  readSerialNonBlocking(Serial, Serial, usbCmdBuffer, usbCmdIndex);

  updateGate();
  updateTray();
  updateDistanceMeasurement();

  if (gateState == GATE_IDLE) {
    updateGatePositionFromSwitches();
  }

  if (trayState == TRAY_IDLE) {
    updateTrayPositionFromSwitches();
  }
}

// =========================
// Serial parser zonder String
// =========================
void readSerialNonBlocking(Stream &input, Print &output, char *cmdBuffer, byte &cmdIndex) {
  while (input.available() > 0) {
    char c = input.read();

    if (c == '\r') {
      continue;
    }

    if (c == '\n') {
      cmdBuffer[cmdIndex] = '\0';

      if (cmdIndex > 0) {
        processCommand(output, cmdBuffer);
      }

      cmdIndex = 0;
      return;
    }

    if (cmdIndex < CMD_BUFFER_SIZE - 1) {
      cmdBuffer[cmdIndex++] = c;
    } else {
      cmdIndex = 0;
      output.println("ERR:BUFFER_OVERFLOW");
      return;
    }
  }
}

// =========================
// Command processor
// Exact 1 antwoord per command
// =========================
void processCommand(Print &output, const char *cmd) {
  if (strcmp(cmd, "GATE_OPEN") == 0) {
    updateGatePositionFromSwitches();
    if (hasGateStopConflict()) {
      stopGate();
      gateState = GATE_IDLE;
      output.println("ERR:GATE_STOP_CONFLICT");
      return;
    }
    if (isGateOpenStopPressed()) {
      stopGate();
      gateState = GATE_IDLE;
      gatePosition = GATE_UP;
    } else {
      gateState = GATE_OPENING;
      servoGate.write(GATE_OPEN_SPEED);
    }
    output.println("ACK:GATE_OPEN");
  }

  else if (strcmp(cmd, "GATE_CLOSE") == 0) {
    updateGatePositionFromSwitches();
    if (hasGateStopConflict()) {
      stopGate();
      gateState = GATE_IDLE;
      output.println("ERR:GATE_STOP_CONFLICT");
      return;
    }
    if (isGateCloseStopPressed()) {
      stopGate();
      gateState = GATE_IDLE;
      gatePosition = GATE_DOWN;
    } else {
      gateState = GATE_CLOSING;
      servoGate.write(GATE_CLOSE_SPEED);
    }
    output.println("ACK:GATE_CLOSE");
  }

  else if (strcmp(cmd, "GATE_STOP") == 0) {
    stopGate();
    gateState = GATE_IDLE;
    updateGatePositionFromSwitches();
    output.println("ACK:GATE_STOP");
  }

  else if (strcmp(cmd, "TRAY_OUT") == 0) {
    updateTrayPositionFromSwitches();
    if (hasTrayStopConflict()) {
      stopTray();
      trayState = TRAY_IDLE;
      output.println("ERR:TRAY_STOP_CONFLICT");
      return;
    }
    if (isTrayOutStopPressed()) {
      stopTray();
      trayState = TRAY_IDLE;
      trayPosition = TRAY_OUT_POS;
    } else {
      trayState = TRAY_OPENING;
      servoPhoneLoader.write(TRAY_OUT_SPEED);
    }
    output.println("ACK:TRAY_OUT");
  }

  else if (strcmp(cmd, "TRAY_IN") == 0) {
    updateTrayPositionFromSwitches();
    if (hasTrayStopConflict()) {
      stopTray();
      trayState = TRAY_IDLE;
      output.println("ERR:TRAY_STOP_CONFLICT");
      return;
    }
    if (isTrayInStopPressed()) {
      stopTray();
      trayState = TRAY_IDLE;
      trayPosition = TRAY_IN_POS;
    } else {
      trayState = TRAY_CLOSING;
      servoPhoneLoader.write(TRAY_IN_SPEED);
    }
    output.println("ACK:TRAY_IN");
  }

  else if (strcmp(cmd, "TRAY_STOP") == 0) {
    stopTray();
    trayState = TRAY_IDLE;
    updateTrayPositionFromSwitches();
    output.println("ACK:TRAY_STOP");
  }

  else if (strncmp(cmd, "WRIST1_ANGLE:", 13) == 0) {
    int angle = atoi(cmd + 13);
    setWrist1Angle(angle);
    output.print("ACK:WRIST1_ANGLE=");
    output.println(wrist1Angle);
  }

  else if (strncmp(cmd, "WRIST2_ANGLE:", 13) == 0) {
    int angle = atoi(cmd + 13);
    setWrist2Angle(angle);
    output.print("ACK:WRIST2_ANGLE=");
    output.println(wrist2Angle);
  }

  else if (strncmp(cmd, "WRIST2_US:", 10) == 0) {
    int pulseUs = atoi(cmd + 10);
    setWrist2Microseconds(pulseUs);
    output.print("ACK:WRIST2_US=");
    output.print(wrist2CurrentUs);
    output.print(",LOGICAL=");
    output.print(wrist2Angle);
    output.print(",PHYSICAL=");
    output.println(wrist2PhysicalAngle);
  }

  else if (strcmp(cmd, "WRIST_HOME") == 0) {
    setWrist1Angle(WRIST1_LOGICAL_CENTER_ANGLE);
    setWrist2Angle(0);
    output.println("ACK:WRIST_HOME");
  }

  else if (strcmp(cmd, "WRIST1_LEFT") == 0) {
    setWrist1Angle(WRIST1_LOGICAL_MIN_ANGLE);
    output.println("ACK:WRIST1_LEFT");
  }

  else if (strcmp(cmd, "WRIST1_CENTER") == 0) {
    setWrist1Angle(WRIST1_LOGICAL_CENTER_ANGLE);
    output.println("ACK:WRIST1_CENTER");
  }

  else if (strcmp(cmd, "WRIST1_RIGHT") == 0) {
    setWrist1Angle(WRIST1_LOGICAL_MAX_ANGLE);
    output.println("ACK:WRIST1_RIGHT");
  }

  else if (strcmp(cmd, "WRIST2_LEFT") == 0) {
    setWrist2Angle(-90);
    output.println("ACK:WRIST2_LEFT");
  }

  else if (strcmp(cmd, "WRIST2_CENTER") == 0) {
    setWrist2Angle(0);
    output.println("ACK:WRIST2_CENTER");
  }

  else if (strcmp(cmd, "WRIST2_RIGHT") == 0) {
    setWrist2Angle(90);
    output.println("ACK:WRIST2_RIGHT");
  }

  else if (strcmp(cmd, "VAC1_ON") == 0) {
    digitalWrite(vacuumMotor1Pin, HIGH);
    output.println("ACK:VAC1_ON");
  }

  else if (strcmp(cmd, "VAC1_OFF") == 0) {
    digitalWrite(vacuumMotor1Pin, LOW);
    output.println("ACK:VAC1_OFF");
  }

  else if (strcmp(cmd, "VAC2_ON") == 0) {
    digitalWrite(vacuumMotor2Pin, HIGH);
    output.println("ACK:VAC2_ON");
  }

  else if (strcmp(cmd, "VAC2_OFF") == 0) {
    digitalWrite(vacuumMotor2Pin, LOW);
    output.println("ACK:VAC2_OFF");
  }

  else if (strcmp(cmd, "VAC_ALL_ON") == 0) {
    digitalWrite(vacuumMotor1Pin, HIGH);
    digitalWrite(vacuumMotor2Pin, HIGH);
    output.println("ACK:VAC_ALL_ON");
  }

  else if (strcmp(cmd, "VAC_ALL_OFF") == 0) {
    digitalWrite(vacuumMotor1Pin, LOW);
    digitalWrite(vacuumMotor2Pin, LOW);
    output.println("ACK:VAC_ALL_OFF");
  }

  else if (strcmp(cmd, "VALVE1_ON") == 0) {
    digitalWrite(valve1Pin, HIGH);
    output.println("ACK:VALVE1_ON");
  }

  else if (strcmp(cmd, "VALVE1_OFF") == 0) {
    digitalWrite(valve1Pin, LOW);
    output.println("ACK:VALVE1_OFF");
  }

  else if (strcmp(cmd, "VALVE2_ON") == 0) {
    digitalWrite(valve2Pin, HIGH);
    output.println("ACK:VALVE2_ON");
  }

  else if (strcmp(cmd, "VALVE2_OFF") == 0) {
    digitalWrite(valve2Pin, LOW);
    output.println("ACK:VALVE2_OFF");
  }

  else if (strcmp(cmd, "VALVE_ALL_ON") == 0) {
    digitalWrite(valve1Pin, HIGH);
    digitalWrite(valve2Pin, HIGH);
    output.println("ACK:VALVE_ALL_ON");
  }

  else if (strcmp(cmd, "VALVE_ALL_OFF") == 0) {
    digitalWrite(valve1Pin, LOW);
    digitalWrite(valve2Pin, LOW);
    output.println("ACK:VALVE_ALL_OFF");
  }

  else if (strcmp(cmd, "DISTANCE_MM") == 0) {
    updateDistanceMeasurement();

    output.print("ACK:DISTANCE_MM=");

    if (!distanceSensorOk) {
      output.println("ERROR");
    } else if (lastDistanceMm == 0) {
      output.println("NA");
    } else {
      output.println(lastDistanceMm);
    }
  }

  else if (strcmp(cmd, "DISTANCE_STATUS") == 0) {
    updateDistanceMeasurement();

    output.print("ACK:DISTANCE_STATUS=");

    if (!distanceSensorOk) {
      output.println("ERROR");
    } else {
      output.print("OK,VALID=");
      output.print(hasValidDistanceMeasurement() ? 1 : 0);
      output.print(",DISPLAY_MM=");
      if (hasDisplayDistanceMeasurement()) {
        output.print(lastDisplayDistanceMm);
      } else {
        output.print("NA");
      }
      output.print(",RANGE_STATUS=");
      output.print(lastDistanceRangeStatus);
      output.print(",RAW_MM=");
      output.print(lastRawDistanceMm);
      output.print(",LAST_MM=");
      output.print(lastDistanceMm);
      output.print(",AGE_MS=");

      if (lastDistanceUpdateMs > 0) {
        output.println(millis() - lastDistanceUpdateMs);
      } else {
        output.println("NA");
      }
    }
  }

  else if (strcmp(cmd, "GATE_POS") == 0) {
    output.print("ACK:GATE_POS=");
    printGatePositionValue(output);
  }

  else if (strcmp(cmd, "TRAY_POS") == 0) {
    output.print("ACK:TRAY_POS=");
    printTrayPositionValue(output);
  }

  else if (strcmp(cmd, "STOP_ALL") == 0) {
    stopGate();
    stopTray();

    gateState = GATE_IDLE;
    trayState = TRAY_IDLE;

    digitalWrite(vacuumMotor1Pin, LOW);
    digitalWrite(vacuumMotor2Pin, LOW);
    digitalWrite(valve1Pin, LOW);
    digitalWrite(valve2Pin, LOW);

    updateGatePositionFromSwitches();
    updateTrayPositionFromSwitches();

    output.println("ACK:STOP_ALL");
  }

  else if (strcmp(cmd, "STATUS") == 0) {
    printStatus(output);
  }

  else {
    output.print("ERR:UNKNOWN_COMMAND=");
    output.println(cmd);
  }
}

// =========================
// Distance sensor
// =========================
void initDistanceSensor() {
  int initStatus = distanceSensor.init();
  distanceSensorOk = (initStatus == 0);

  if (!distanceSensorOk) {
    lastDistanceRangeStatus = 255;
    return;
  }

  distanceSensor.setDistanceModeLong();
  distanceSensor.setTimingBudgetInMs(100);
  distanceSensor.setIntermeasurementPeriod(200);
  distanceSensor.startRanging();

  unsigned long started = millis();

  while (millis() - started < 500) {
    if (distanceSensor.checkForDataReady()) {
      uint8_t rangeStatus = distanceSensor.getRangeStatus();
      uint16_t distance = distanceSensor.getDistance();
      distanceSensor.clearInterrupt();

      lastRawDistanceMm = distance;
      lastDistanceRangeStatus = rangeStatus;
      updateDisplayDistance(distance, rangeStatus);

      if (rangeStatus == 0 && distance > 0) {
        lastDistanceMm = distance;
        lastDistanceUpdateMs = millis();
      }

      break;
    }

    delay(5);
  }
}

void updateDistanceMeasurement() {
  if (!distanceSensorOk) return;
  if (!distanceSensor.checkForDataReady()) return;

  uint8_t rangeStatus = distanceSensor.getRangeStatus();
  uint16_t distance = distanceSensor.getDistance();
  distanceSensor.clearInterrupt();

  lastRawDistanceMm = distance;
  lastDistanceRangeStatus = rangeStatus;
  updateDisplayDistance(distance, rangeStatus);

  if (rangeStatus == 0 && distance > 0) {
    lastDistanceMm = distance;
    lastDistanceUpdateMs = millis();
  }
}

void updateDisplayDistance(uint16_t distance, uint8_t rangeStatus) {
  if (rangeStatus == 0 && distance > 0) {
    lastDisplayDistanceMm = distance;
    return;
  }

  if (distance > 0) {
    lastDisplayDistanceMm = distance;
  }
}

bool hasValidDistanceMeasurement() {
  return distanceSensorOk && lastDistanceMm > 0 && lastDistanceRangeStatus == 0;
}

bool hasDisplayDistanceMeasurement() {
  return distanceSensorOk && lastDisplayDistanceMm > 0;
}

// =========================
// Gate update logic
// Geen Serial prints hier
// =========================
void updateGate() {
  switch (gateState) {
    case GATE_OPENING:
      if (isGateOpenStopPressed()) {
        stopGate();
        gateState = GATE_IDLE;
        gatePosition = GATE_UP;
      }
      break;

    case GATE_CLOSING:
      if (isGateCloseStopPressed()) {
        stopGate();
        gateState = GATE_IDLE;
        gatePosition = GATE_DOWN;
      }
      break;

    case GATE_IDLE:
      break;
  }
}

// =========================
// Tray update logic
// Geen Serial prints hier
// =========================
void updateTray() {
  switch (trayState) {
    case TRAY_OPENING:
      if (isTrayOutStopPressed()) {
        stopTray();
        trayState = TRAY_IDLE;
        trayPosition = TRAY_OUT_POS;
      }
      break;

    case TRAY_CLOSING:
      if (isTrayInStopPressed()) {
        stopTray();
        trayState = TRAY_IDLE;
        trayPosition = TRAY_IN_POS;
      }
      break;

    case TRAY_IDLE:
      break;
  }
}

// =========================
// Servo helpers
// =========================
void stopGate() {
  servoGate.write(SERVO_STOP);
}

void stopTray() {
  servoPhoneLoader.write(SERVO_STOP);
}

bool isGateOpenStopPressed() {
  return digitalRead(gateOpenSwitch) == STOPPER_SWITCH_TRIGGERED_LEVEL;
}

bool isGateCloseStopPressed() {
  return digitalRead(gateCloseSwitch) == STOPPER_SWITCH_TRIGGERED_LEVEL;
}

bool hasGateStopConflict() {
  return isGateOpenStopPressed() && isGateCloseStopPressed();
}

bool isTrayOutStopPressed() {
  return digitalRead(trayOutSwitch) == STOPPER_SWITCH_TRIGGERED_LEVEL;
}

bool isTrayInStopPressed() {
  return digitalRead(trayInSwitch) == STOPPER_SWITCH_TRIGGERED_LEVEL;
}

bool hasTrayStopConflict() {
  return isTrayOutStopPressed() && isTrayInStopPressed();
}

int angleToMicroseconds(int angle, int minAngle, int maxAngle, int minUs, int maxUs) {
  angle = constrain(angle, minAngle, maxAngle);
  return map(angle, minAngle, maxAngle, minUs, maxUs);
}

int wrist1LogicalToPhysicalAngle(int logicalAngle) {
  int clampedLogical = constrain(logicalAngle, WRIST1_LOGICAL_MIN_ANGLE, WRIST1_LOGICAL_MAX_ANGLE);
  if (clampedLogical >= WRIST1_LOGICAL_CENTER_ANGLE) {
    return map(
      clampedLogical,
      WRIST1_LOGICAL_CENTER_ANGLE,
      WRIST1_LOGICAL_MAX_ANGLE,
      WRIST1_CENTER_PHYSICAL_ANGLE,
      WRIST1_RIGHT_PHYSICAL_ANGLE
    );
  }
  return map(
    clampedLogical,
    WRIST1_LOGICAL_MIN_ANGLE,
    WRIST1_LOGICAL_CENTER_ANGLE,
    WRIST1_LEFT_PHYSICAL_ANGLE,
    WRIST1_CENTER_PHYSICAL_ANGLE
  );
}

int wrist1LogicalToMicroseconds(int logicalAngle) {
  int clampedLogical = constrain(logicalAngle, WRIST1_LOGICAL_MIN_ANGLE, WRIST1_LOGICAL_MAX_ANGLE);
  if (clampedLogical >= WRIST1_LOGICAL_CENTER_ANGLE) {
    return map(
      clampedLogical,
      WRIST1_LOGICAL_CENTER_ANGLE,
      WRIST1_LOGICAL_MAX_ANGLE,
      WRIST1_CENTER_US,
      WRIST1_RIGHT_US
    );
  }
  return map(
    clampedLogical,
    WRIST1_LOGICAL_MIN_ANGLE,
    WRIST1_LOGICAL_CENTER_ANGLE,
    WRIST1_LEFT_US,
    WRIST1_CENTER_US
  );
}

int wrist2LogicalToPhysicalAngle(int logicalAngle) {
  int clampedLogical = constrain(logicalAngle, WRIST2_LOGICAL_MIN_ANGLE, WRIST2_LOGICAL_MAX_ANGLE);
  if (clampedLogical >= 0) {
    return map(clampedLogical, 0, WRIST2_LOGICAL_MAX_ANGLE, WRIST2_CENTER_PHYSICAL_ANGLE, WRIST2_RIGHT_PHYSICAL_ANGLE);
  }
  return map(clampedLogical, WRIST2_LOGICAL_MIN_ANGLE, 0, WRIST2_LEFT_PHYSICAL_ANGLE, WRIST2_CENTER_PHYSICAL_ANGLE);
}

int wrist2LogicalToMicroseconds(int logicalAngle) {
  int clampedLogical = constrain(logicalAngle, WRIST2_LOGICAL_MIN_ANGLE, WRIST2_LOGICAL_MAX_ANGLE);
  if (clampedLogical >= 0) {
    return map(clampedLogical, 0, WRIST2_LOGICAL_MAX_ANGLE, WRIST2_CENTER_US, WRIST2_RIGHT_US);
  }
  return map(clampedLogical, WRIST2_LOGICAL_MIN_ANGLE, 0, WRIST2_LEFT_US, WRIST2_CENTER_US);
}

int wrist2MicrosecondsToPhysicalAngle(int pulseUs) {
  int clampedUs = constrain(pulseUs, WRIST2_DIRECT_MIN_US, WRIST2_DIRECT_MAX_US);
  if (clampedUs >= WRIST2_CENTER_US) {
    return map(clampedUs, WRIST2_CENTER_US, WRIST2_RIGHT_US, WRIST2_CENTER_PHYSICAL_ANGLE, WRIST2_RIGHT_PHYSICAL_ANGLE);
  }
  return map(clampedUs, WRIST2_LEFT_US, WRIST2_CENTER_US, WRIST2_LEFT_PHYSICAL_ANGLE, WRIST2_CENTER_PHYSICAL_ANGLE);
}

int wrist2MicrosecondsToLogicalAngle(int pulseUs) {
  int clampedUs = constrain(pulseUs, WRIST2_DIRECT_MIN_US, WRIST2_DIRECT_MAX_US);
  if (clampedUs >= WRIST2_CENTER_US) {
    return map(clampedUs, WRIST2_CENTER_US, WRIST2_RIGHT_US, 0, WRIST2_LOGICAL_MAX_ANGLE);
  }
  return map(clampedUs, WRIST2_LEFT_US, WRIST2_CENTER_US, WRIST2_LOGICAL_MIN_ANGLE, 0);
}

void setWrist1Angle(int logicalAngle) {
  wrist1Angle = constrain(logicalAngle, WRIST1_LOGICAL_MIN_ANGLE, WRIST1_LOGICAL_MAX_ANGLE);
  wrist1PhysicalAngle = wrist1LogicalToPhysicalAngle(wrist1Angle);
  wrist1CurrentUs = wrist1LogicalToMicroseconds(wrist1Angle);
  servoWrist1.writeMicroseconds(wrist1CurrentUs);
}
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

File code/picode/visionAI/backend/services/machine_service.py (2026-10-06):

import os
import re
import threading
import time
from typing import Callable, Optional

from fastapi import HTTPException
import serial  # type: ignore


GATE_POSITION_PATTERN = re.compile(r"^(?:ACK:)?GATE_POS=(UP|DOWN|UNKNOWN)$")
STATUS_LINE_PATTERN = re.compile(r"^(?:ACK:STATUS,)?gateState=.*\btrayInSw=\d+\s*$")
_LEONARDO_SERIAL_LOCK = threading.RLock()
_LEONARDO_SERIAL: Optional[serial.Serial] = None
_LEONARDO_SERIAL_PORT = ""
_LEONARDO_SERIAL_BAUD = 0
_WRIST_ANGLE_CACHE = {1: int(os.getenv("APP_WRIST1_HOME_ANGLE", "93")), 2: 90}
_LAST_STATUS_VALUES: dict[str, str] = {}
_LAST_STATUS_RESPONSE: list[str] = []
_LAST_STATUS_AT = 0.0


def _get_leonardo_port() -> str:
    return os.getenv("APP_LEONARDO_PORT", os.getenv("APP_ARDUINO_PORT", "/dev/ttyACM0"))


def _get_leonardo_baud() -> int:
    return int(os.getenv("APP_LEONARDO_BAUD", "115200"))


def _get_leonardo_read_timeout_s() -> float:
    return max(0.1, float(os.getenv("APP_LEONARDO_READ_TIMEOUT_S", "0.8")))


def _get_leonardo_open_delay_s() -> float:
    return max(0.0, float(os.getenv("APP_LEONARDO_OPEN_DELAY_S", "0.35")))


def _get_leonardo_command_open_delay_s() -> float:
    return max(0.0, float(os.getenv("APP_LEONARDO_COMMAND_OPEN_DELAY_S", "0.8")))


def _get_leonardo_post_write_hold_s() -> float:
    return max(0.0, float(os.getenv("APP_LEONARDO_POST_WRITE_HOLD_S", "0.25")))


def _get_leonardo_write_retry_delay_s() -> float:
    return max(0.0, float(os.getenv("APP_LEONARDO_WRITE_RETRY_DELAY_S", "0.35")))


def _get_leonardo_write_timeout_s() -> float:
    return max(0.1, float(os.getenv("APP_LEONARDO_WRITE_TIMEOUT_S", "1.0")))


def _hold_leonardo_control_lines_inactive() -> bool:
    return os.getenv("APP_LEONARDO_CONTROL_LINES_INACTIVE", "0").strip().lower() in {"1", "true", "yes", "on"}


def _use_persistent_leonardo_serial() -> bool:
    return os.getenv("APP_LEONARDO_PERSISTENT_SERIAL", "0").strip().lower() in {"1", "true", "yes", "on"}


def _get_leonardo_status_retries() -> int:
    return max(1, int(os.getenv("APP_LEONARDO_STATUS_RETRIES", "3")))


def _get_leonardo_status_retry_delay_s() -> float:
    return max(0.0, float(os.getenv("APP_LEONARDO_STATUS_RETRY_DELAY_S", "0.25")))


def _get_leonardo_poll_status_timeout_s() -> float:
    return max(0.05, float(os.getenv("APP_LEONARDO_POLL_STATUS_TIMEOUT_S", "0.1")))


def _get_wrist_dwell_ms() -> int:
    return int(os.getenv("APP_WRIST_DWELL_MS", "600"))


def _get_wrist_smooth_step_deg() -> int:
    return max(1, int(os.getenv("APP_WRIST_SMOOTH_STEP_DEG", "2")))


def _get_wrist_smooth_delay_ms() -> int:
    return max(0, int(os.getenv("APP_WRIST_SMOOTH_DELAY_MS", "25")))


def _get_wrist_min_angle(wrist_index: Optional[int] = None) -> int:
    if wrist_index in (1, 2):
        specific = os.getenv(f"APP_WRIST{wrist_index}_MIN_ANGLE")
        if specific is not None:
            return int(specific)
    return int(os.getenv("APP_WRIST_MIN_ANGLE", "-5"))


def _get_wrist_max_angle(wrist_index: Optional[int] = None) -> int:
    if wrist_index in (1, 2):
        specific = os.getenv(f"APP_WRIST{wrist_index}_MAX_ANGLE")
        if specific is not None:
            return int(specific)
    return int(os.getenv("APP_WRIST_MAX_ANGLE", "182"))


def _clamp_wrist_angle(angle: int, wrist_index: Optional[int] = None) -> int:
    min_angle = _get_wrist_min_angle(wrist_index)
    max_angle = _get_wrist_max_angle(wrist_index)
    if min_angle > max_angle:
        min_angle, max_angle = max_angle, min_angle
    return max(min_angle, min(max_angle, int(angle)))


def wrist_min_angle(wrist_index: Optional[int] = None) -> int:
    return min(_get_wrist_min_angle(wrist_index), _get_wrist_max_angle(wrist_index))


def wrist_max_angle(wrist_index: Optional[int] = None) -> int:
    return max(_get_wrist_min_angle(wrist_index), _get_wrist_max_angle(wrist_index))


def wrist1_home_angle() -> int:
    return _clamp_wrist_angle(int(os.getenv("APP_WRIST1_HOME_ANGLE", "93")), 1)


def _close_leonardo_serial():
    global _LEONARDO_SERIAL, _LEONARDO_SERIAL_PORT, _LEONARDO_SERIAL_BAUD
    if _LEONARDO_SERIAL is not None:
        try:
            _LEONARDO_SERIAL.close()
        except Exception:
            pass
    _LEONARDO_SERIAL = None
    _LEONARDO_SERIAL_PORT = ""
    _LEONARDO_SERIAL_BAUD = 0


def _reset_serial_buffers(ser: serial.Serial):
    if hasattr(ser, "reset_input_buffer"):
        ser.reset_input_buffer()
    if hasattr(ser, "reset_output_buffer"):
        try:
            ser.reset_output_buffer()
        except Exception:
            pass


def _write_serial_line(ser: serial.Serial, line: str):
    ser.write((line.strip() + "\n").encode("ascii", errors="ignore"))


def _set_serial_lines_inactive(ser: serial.Serial):
    for line_signal in ("dtr", "rts"):
        if hasattr(ser, line_signal):
            try:
                setattr(ser, line_signal, False)
            except Exception:
                pass


def _set_serial_lines_active(ser: serial.Serial):
    for line_signal in ("dtr", "rts"):
        if hasattr(ser, line_signal):
            try:
                setattr(ser, line_signal, True)
            except Exception:
                pass


def _is_serial_write_timeout(exc: Exception) -> bool:
    if isinstance(exc, serial.SerialTimeoutException):
        return True
    return "write timeout" in str(exc).strip().lower()


def _open_leonardo_serial(port: str, baudrate: int) -> serial.Serial:
    ser = serial.Serial()
    ser.port = port
    ser.baudrate = baudrate
    ser.timeout = 0.2
    ser.write_timeout = _get_leonardo_write_timeout_s()
    if _hold_leonardo_control_lines_inactive():
        _set_serial_lines_inactive(ser)
    ser.open()
    if _hold_leonardo_control_lines_inactive():
        _set_serial_lines_inactive(ser)
    else:
        _set_serial_lines_active(ser)
    _reset_serial_buffers(ser)
    return ser


def _get_leonardo_serial() -> serial.Serial:
    global _LEONARDO_SERIAL, _LEONARDO_SERIAL_PORT, _LEONARDO_SERIAL_BAUD

    port = _get_leonardo_port()
    baudrate = _get_leonardo_baud()
    if (
        _LEONARDO_SERIAL is not None
        and getattr(_LEONARDO_SERIAL, "is_open", True)
        and _LEONARDO_SERIAL_PORT == port
        and _LEONARDO_SERIAL_BAUD == baudrate
    ):
        return _LEONARDO_SERIAL

    _close_leonardo_serial()
    _LEONARDO_SERIAL = _open_leonardo_serial(port, baudrate)
    _LEONARDO_SERIAL_PORT = port
    _LEONARDO_SERIAL_BAUD = baudrate

    open_delay_s = _get_leonardo_open_delay_s()
    if open_delay_s > 0:
        time.sleep(open_delay_s)

    return _LEONARDO_SERIAL
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

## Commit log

2026-03-03 Update README with installation instructions
    Added installation instructions for Arduino Mega and GRBL.
2026-03-09 switch test
2026-05-13 grbl update
2026-05-13 grbl update2
2026-05-13 grbl update3
2026-05-13 grbl update4
2026-05-13 grbl update5
2026-06-17 Fix GRBL port on Pi
2026-10-13 Fix forward and back arm controls
2026-10-13 Reduce homing feed rates
2026-10-13 Wait for GRBL status before sending commands
2026-10-13 Skip Z axis during homing
2026-10-13 Set moderate XY homing speed
2026-10-13 Use Pi camera and hold vacuum motors during scan
2026-10-13 Wait for GRBL status after startup banner
2026-10-13 Update README with Z-axis redesign details
    Added a new improvement related to redesigning the Z-axis with pogo pins.
2026-10-13 Clarify missing CSI camera error
2026-10-13 Add slow arm clearance before automatic scan
2026-10-13 Require tray end-switch before closing gate
